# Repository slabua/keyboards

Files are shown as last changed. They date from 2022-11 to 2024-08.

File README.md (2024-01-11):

# Keyboards
[][GPLurl]

- [AtreuSLB50+](./atreuslb50+/)
  - A hand-wired custom Mechanical Keyboard based on the Raspberry Pi Pico.
- [JeegVa44 ErgoZero Split](./jeegva44ergozero/)
  - A split hand-wired custom Mechanical Keyboard based on the Waveshare RP2040-Zero.
- [Saru48W+](./saru48wplus/)
  - An ortholinear 13x4 hand-wired custom Mechanical Keyboard based on the nice!nano.

[GPLimg]: https://img.shields.io/badge/License-GPLv3-blue.svg
[GPLurl]: https://www.gnu.org/licenses/gpl-3.0

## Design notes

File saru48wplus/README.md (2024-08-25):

# Saru48W+ Mechanical Keyboard
[][GPLurl]
###### tags: `ZMK`
Status: Currently under development.

### An ortholinear 13x4 hand-wired custom Mechanical Keyboard based on the [nice!nano](https://nicekeyboards.com/nice-nano).

My third keyboard designed from scratch, this time with Bluetooth connectivity.

## Components
- 1x nice!nano (ZMK), USB-C and Bluetooth [[Buy]](https://nicekeyboards.com/nice-nano)
- 1x 3.7V 503040 600mAh LiPo battery [[Buy]](https://www.amazon.co.jp/gp/product/B07V22WWRJ)
- 48x switches [[Buy]](https://www.keychron.com/products/low-profile-gateron-mechanical-switch-set)
- 1x EC11 encoder [[Buy]](https://www.aliexpress.com/item/1005002358274622.html)
- 30x M2 5~6mm screws [[Buy]](https://www.amazon.co.jp/gp/product/B08KW4946Z)
- 6x M2 nuts [[Buy]](https://www.amazon.co.jp/dp/B096FKCZ5X)
- 12x M2 10mm stand-offs [[Buy]](https://www.amazon.co.jp/dp/B096FKCZ5X)
- 2x M4 Low profile brass heat inserts [[Buy]](https://www.amazon.co.jp/dp/B09HJY5717)
- 2x M4 6~8mm Socket cap head screws [[Buy]](https://www.amazon.co.jp/dp/B0BY8VXTLV)
- 1x micro switch (power) [[Buy]](https://www.amazon.co.jp/dp/B07F6WH8BV)
- 1x micro push button (bootsel, reset) [[Buy]](https://www.aliexpress.com/item/32907074501.html)
- 3D printed case, plate, feet

## Story
I wanted a more compact portable keyboard with Bluetooth connectivity and an encoder.
Different MCU, different firmware.

## Keymap (dev)
Keymap (http://www.keyboard-layout-editor.com/#/gists/8c13f3b0b67861c5a3c0984de046201e)

## Wiring
Wiring

## Repository
[https://github.com/slabua/keyboards/tree/main/saru48wplus](https://github.com/slabua/keyboards/tree/main/saru48wplus)

## Firmware
[https://github.com/slabua/zmk-config-saru48wplus](https://github.com/slabua/zmk-config-saru48wplus)

## 3D Model
3D model of Saru48W+ rev1 also available on:
Onshape: [[Link] (Coming Soon)](TODO)  
Thingiverse: https://www.thingiverse.com/thing:6428317  
Printables: https://www.printables.com/model/717305-saru48w-rev1

## Some photographs [[More]](./doc/photos.md)


## Build process [[More]](./doc/build.md)


## CAD renders [[More]](./doc/renders.md)


[GPLimg]: https://img.shields.io/badge/License-GPLv3-blue.svg
[GPLurl]: https://www.gnu.org/licenses/gpl-3.0

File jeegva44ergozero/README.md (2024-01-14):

# JeegVa44 ErgoZero Split Mechanical Keyboard
[][GPLurl]
###### tags: `Raspberry Pi` `RaspberryPi` `Raspberry` `Pi` `Pico` `RaspberryPiPico` `MicroPython`
Status: COMPLETED.

### A split hand-wired custom Mechanical Keyboard based on the [Waveshare RP2040-Zero](https://www.waveshare.com/rp2040-zero.htm).

My second keyboard designed from scratch, this time split.

## Components
- 2x RP2040 (KMK on Waveshare RP2040-Zero), USB-C port
- 44x switches
- 2x TRRS breakout boards
- 1x TRRS cable
- 28x M2 5mm screws
- 14x M2 10mm stand-offs
- 4x M4 Low profile brass heat inserts
- 4x M4 6~8mm Socket cap head screws
- 8x 10mm Rubber feet
- 46u Round hole female pin header
- 3D printed case, plate, feet

## Story
I wanted a portable split keyboard with a gentle vertical stagger, sixth column available and four thumb keys.
I also wanted to learn more about proper CAD design, so this time I ditched Blender and I designed everything from scratch in Onshape.

## Keymap (dev)
Keymap (http://www.keyboard-layout-editor.com/#/gists/682da89ee55639fe9fc0c6a14366d514)

## Repository
[https://github.com/slabua/keyboards/tree/main/jeegva44ergozero](https://github.com/slabua/keyboards/tree/main/jeegva44ergozero)

## 3D Model
3D model of JeegVa44 ErgoZero rev1 also available on:  
Onshape: [[Link]](https://cad.onshape.com/documents/5100a1aea8e406302df5bca3/w/c11b98ab1821eb9b6ec6d694/e/c7ba09cd25f0a52e98e90cc7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)  
Thingiverse: https://www.thingiverse.com/thing:5866262  
Printables: https://www.printables.com/model/404303-jeegva44-ergozero-rev1

## Some photographs and renders
















[GPLimg]: https://img.shields.io/badge/License-GPLv3-blue.svg
[GPLurl]: https://www.gnu.org/licenses/gpl-3.0

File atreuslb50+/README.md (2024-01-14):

# AtreuSLB50+ Mechanical Keyboard
[][GPLurl]
###### tags: `Raspberry Pi` `RaspberryPi` `Raspberry` `Pi` `Pico` `RaspberryPiPico` `MicroPython`
Status: COMPLETED.

### A hand-wired custom Mechanical Keyboard based on the [Raspberry Pi Pico](https://www.raspberrypi.org/products/raspberry-pi-pico/).

Finally I had the time to wrap up my little side project started about three months ago, and I thought to share it here. Although inspired by the Atreus, I couldn't quite find the right compromise among the non-split ergo keyboards, so I decided to make my own.

## Components
- 1x RP2040 (KMK on Raspberry Pi Pico), USB-C port
- 50x switches
- 1x SSD1306 128x64px 0.96in IIC OLED display
- 2x EC11 rotary encoders
- 1x EVQWGD001 rotary encoder
- 1x Pimoroni IIC trackball breakout
- 1x Active buzzer
- 2x micro push buttons (bootsel, reset)
- 3D printed case (5-10° tilt), plate, pcb

## Story
The design started from a semi-automated customised process by forking an OpenSCAD hotswap pcb generator repository, subsequently heavily worked on Blender. I had also added cutouts for per-key rgb, but in the end I gave up the idea of hand wiring the LEDs. At least in this version which, for me, has been an insightful experience.
I am slowly finalising the firmware configuration and I will eventually put it on github as usual. Wiring diagram and key layout will come along later.

## Keymap (dev)
Keymap (http://www.keyboard-layout-editor.com/#/gists/e1e9e5b6f24ec3cef3d0345b61fd87a2)

## Repository
[https://github.com/slabua/keyboards/tree/main/atreuslb50+](https://github.com/slabua/keyboards/tree/main/atreuslb50+)

## 3D Model
3D model of AtreuSLB50+ rev1 also available on:  
Thingiverse: https://www.thingiverse.com/thing:5458679  
Printables: https://www.printables.com/model/262446-atreuslb50-rev1

## Some photographs




















[GPLimg]: https://img.shields.io/badge/License-GPLv3-blue.svg
[GPLurl]: https://www.gnu.org/licenses/gpl-3.0

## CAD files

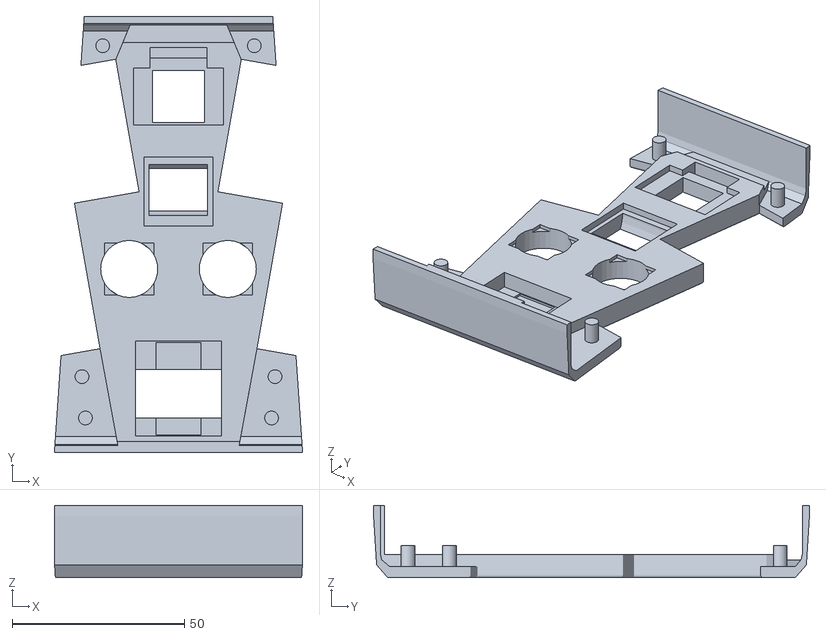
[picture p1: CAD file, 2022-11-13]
atreuslb50+/cad/rev1/AtreuSLB50-TopCenter.stl
72.0 x 126.5 x 21.0

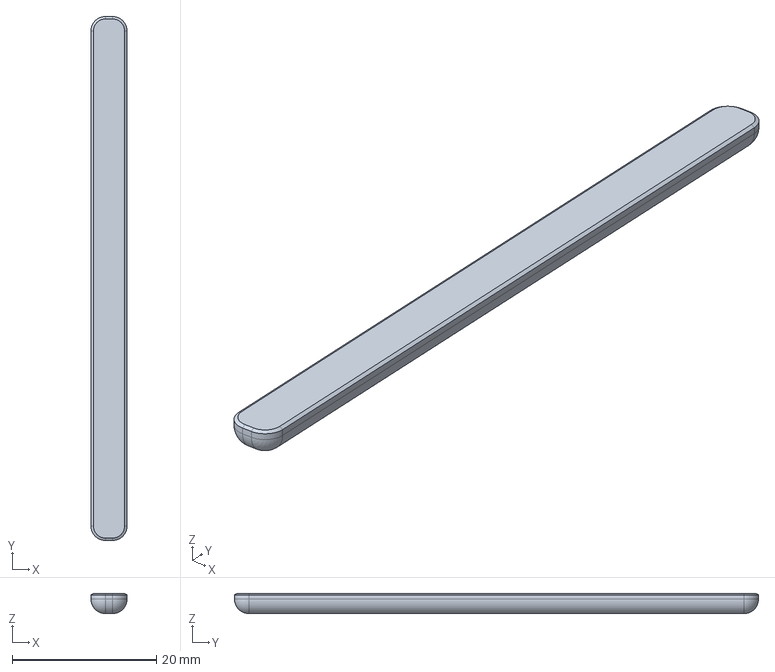
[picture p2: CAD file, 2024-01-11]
saru48wplus/cad/rev1/step/Saru48wPlus - FootLow.step
5.00 x 72.6 x 2.80 mm

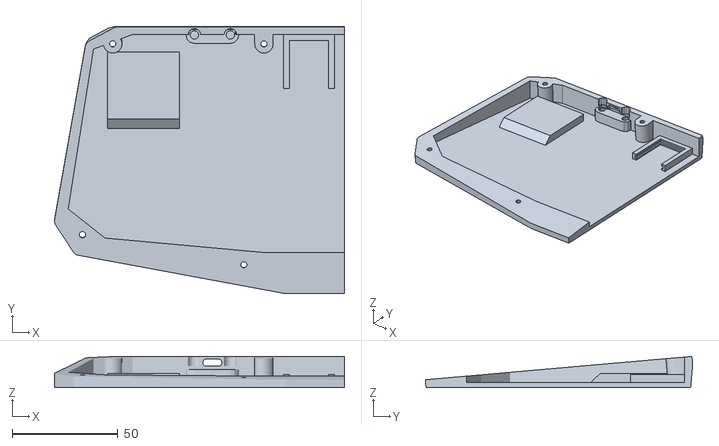
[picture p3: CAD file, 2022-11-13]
atreuslb50+/cad/rev1/AtreuSLB50-BottomLeft.stl
137.0 x 126.4 x 14.7

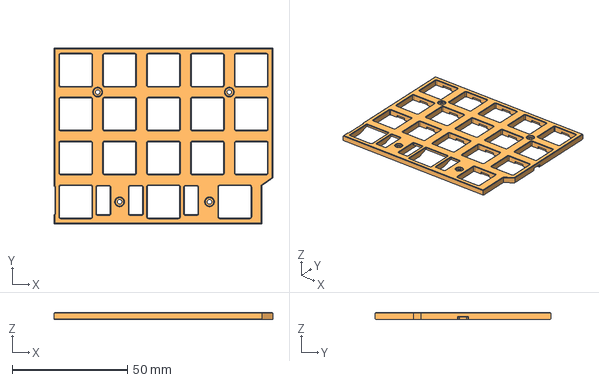
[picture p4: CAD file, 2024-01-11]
saru48wplus/cad/rev1/step/Saru48wPlus - PlateC (CherryMX).step
95.0 x 76.2 x 3.00 mm

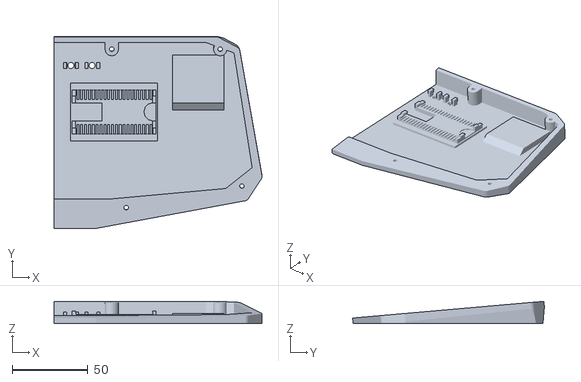
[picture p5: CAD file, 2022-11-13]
atreuslb50+/cad/rev1/AtreuSLB50-BottomRight.stl
137.0 x 126.4 x 14.7

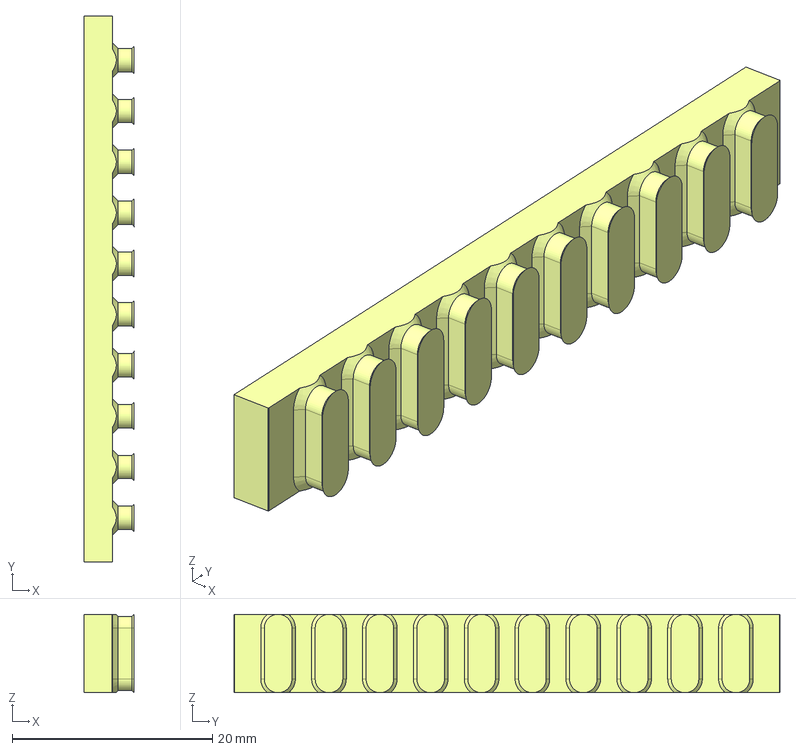
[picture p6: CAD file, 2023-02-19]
jeegva44ergozero/cad/rev1/step/JeegVa44ErgoZero-SlitsCoverR.step
5.00 x 54.5 x 7.84 mm

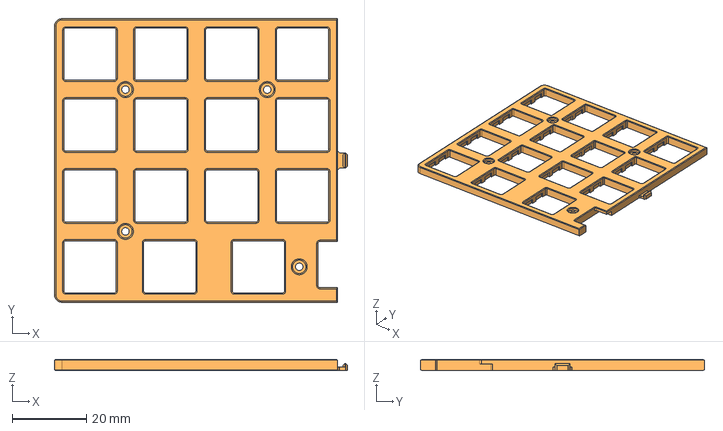
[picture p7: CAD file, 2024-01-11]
saru48wplus/cad/rev1/step/Saru48wPlus - PlateL (GateronLowProfile).step
78.7 x 76.2 x 3.00 mm

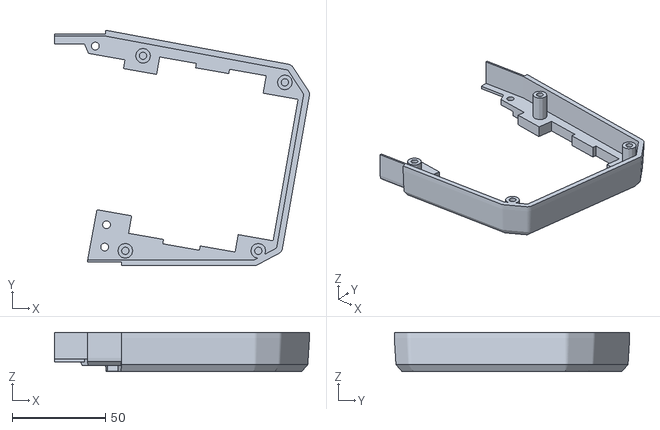
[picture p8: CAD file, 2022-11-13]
atreuslb50+/cad/rev1/AtreuSLB50-TopRight.stl
137.0 x 126.5 x 21.0

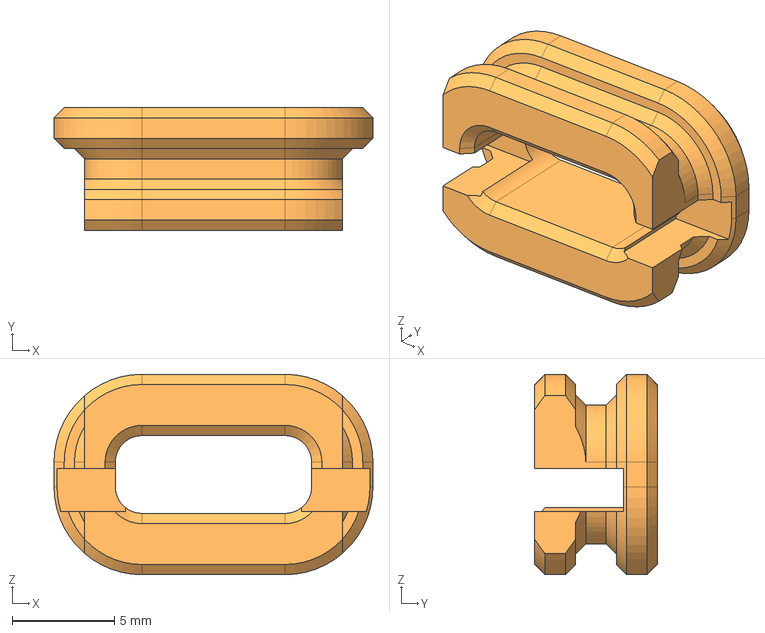
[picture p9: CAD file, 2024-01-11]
saru48wplus/cad/rev1/step/Saru48wPlus - USB Ring.step
15.6 x 6.00 x 9.80 mm

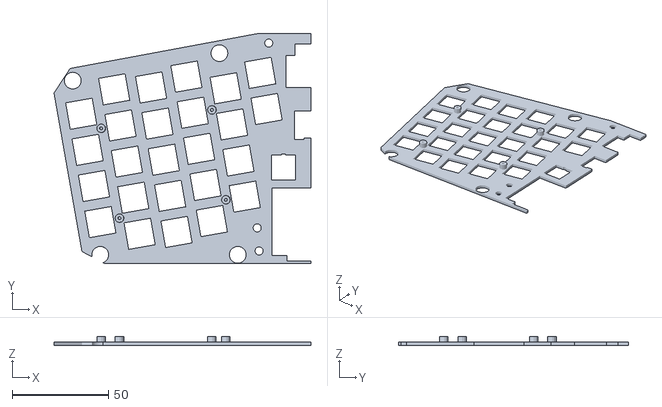
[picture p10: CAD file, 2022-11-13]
atreuslb50+/cad/rev1/AtreuSLB50-PlateLeft.stl
133.5 x 119.5 x 4.80

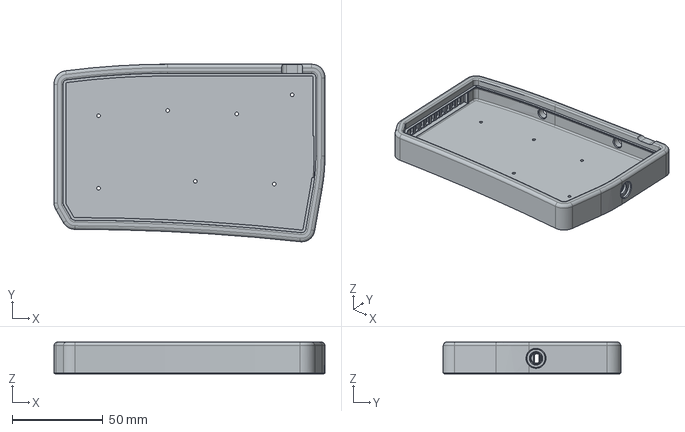
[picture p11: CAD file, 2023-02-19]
jeegva44ergozero/cad/rev1/step/JeegVa44ErgoZero-CaseL.step
149.4 x 97.9 x 17.6 mm

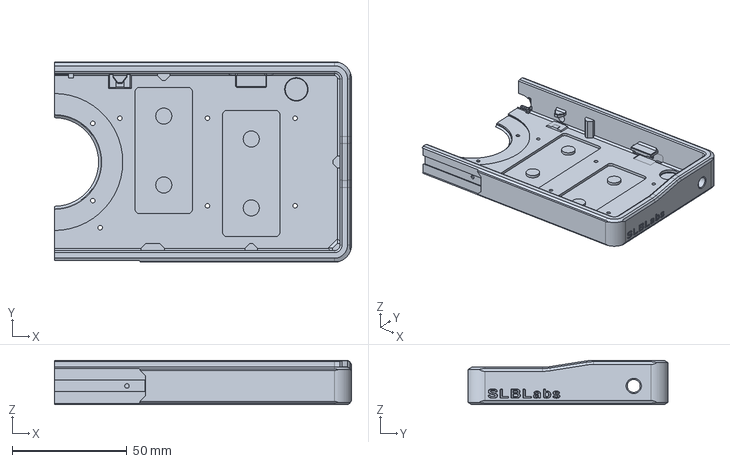
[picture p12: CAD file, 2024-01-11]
saru48wplus/cad/rev1/step/Saru48wPlus - CaseR.step
129.2 x 87.2 x 19.3 mm

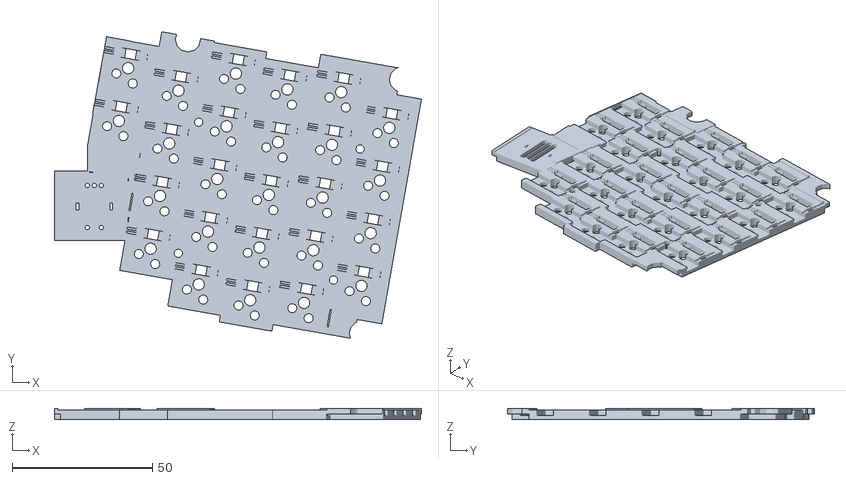
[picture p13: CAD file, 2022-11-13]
atreuslb50+/cad/rev1/AtreuSLB50-PcbRight.stl
130.7 x 109.2 x 4.00

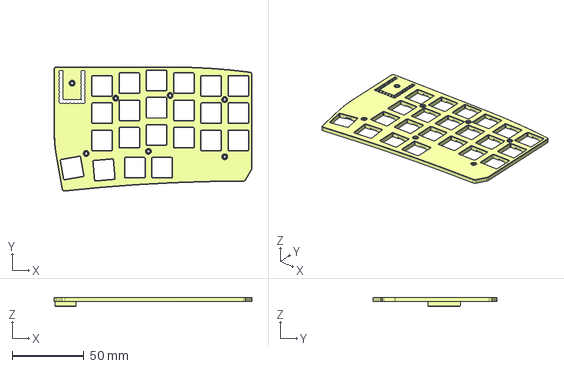
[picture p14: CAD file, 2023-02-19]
jeegva44ergozero/cad/rev1/step/JeegVa44ErgoZero-PlateR.step
138.4 x 86.9 x 6.50 mm

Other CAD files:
jeegva44ergozero/cad/rev1/step/JeegVa44ErgoZero-CaseR-noSlits.step
jeegva44ergozero/cad/rev1/step/JeegVa44ErgoZero-CaseL-noSlits.step
jeegva44ergozero/cad/rev1/step/JeegVa44ErgoZero-SlitsCoverL.step
saru48wplus/cad/rev1/step/Saru48wPlus - PlateC (GateronLowProfile).step
atreuslb50+/cad/rev1/AtreuSLB50-Foot.stl
atreuslb50+/cad/rev1/AtreuSLB50-PcbLeft.stl
atreuslb50+/cad/rev1/AtreuSLB50-PlateRight.stl
atreuslb50+/cad/rev1/AtreuSLB50-TopLeft.stl
jeegva44ergozero/cad/rev1/step/JeegVa44ErgoZero-CaseR.step
jeegva44ergozero/cad/rev1/step/JeegVa44ErgoZero-ErgoFoot.step
jeegva44ergozero/cad/rev1/step/JeegVa44ErgoZero-PlateL.step
jeegva44ergozero/cad/rev1/stl/JeegVa44ErgoZero-ErgoFoot.stl
jeegva44ergozero/cad/rev1/stl/JeegVa44ErgoZero-SlitsCoverL.stl
jeegva44ergozero/cad/rev1/stl/JeegVa44ErgoZero-SlitsCoverR.stl
saru48wplus/cad/rev1/step/Saru48wPlus - Badge.step
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













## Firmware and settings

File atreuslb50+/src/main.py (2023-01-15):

import board
import pwmio
import time

from kb import KMKKeyboard
# import logos

from kmk.consts import UnicodeMode
from kmk.handlers.sequences import compile_unicode_string_sequences as cuss
from kmk.handlers.sequences import send_string
from kmk.keys import KC

from kmk.extensions.buzzer import BuzzerType
from kmk.extensions.lock_status import LockStatus
from kmk.extensions.media_keys import MediaKeys
from kmk.extensions.oled_1306 import DisplayOLED, LogoScene, StatusScene  # , KeypressesScene
# from kmk.extensions.RGB import RGB
# from kmk.extensions.wpm import WPM
from kmk.modules.encoder import EncoderHandler
from kmk.modules.layers import Layers
from kmk.modules.modtap import ModTap
from kmk.modules.mouse_keys import MouseKeys
from kmk.modules.oneshot import OneShot
from kmk.modules.pimoroni_trackball import Trackball, TrackballMode, PointingHandler, KeyHandler, ScrollHandler, ScrollDirection
from kmk.modules.tapdance import TapDance
from micropython import const

import busio as io
i2c = io.I2C(scl=board.GP1, sda=board.GP0)

keyboard = KMKKeyboard()

# Extensions
buzzertype = BuzzerType(enabled=False)
locks = LockStatus()
mediakeys = MediaKeys()
# rgb = RGB(pixel_pin=14, num_pixels=1)
# wpm = WPM(debug=False)
keyboard.extensions = [locks, mediakeys, buzzertype]  # , wpm]  # , rgb]
# keyboard.extensions = [locks, mediakeys]  # , wpm]  # , rgb]

# Modules
layers = Layers()
modtap = ModTap()
modtap.tap_time = 250
mousekeys = MouseKeys()
oneshot = OneShot()
oneshot.tap_time = 1000
tapdance = TapDance()
tapdance.tap_time = 750

# Rotary encoders
encoders = EncoderHandler()
encoders.pins = (
    (board.GP14, board.GP15, None, False, 4),  # encoder L
    (board.GP17, board.GP16, None, False, 4),  # encoder R
    (board.GP12, board.GP13, None, False, 2),  # roller
)

# Trackball
trackball = Trackball(i2c, mode=TrackballMode.MOUSE_MODE, handlers=[
    PointingHandler(),
    # on layer 1 and above use the default pointing behavior
    ScrollHandler(scroll_direction=ScrollDirection.REVERSE),
    # act like an encoder, input arrow keys
    KeyHandler(KC.UP, KC.RIGHT, KC.DOWN, KC.LEFT, KC.ENTER),
])

# OLED
layers_names = ['0. Qwerty', '1. Fun | Num', '2. Sym | Nav',
                '3. Emoji', '4. Tarmak3', '5. Tarmak4', '6. Colemak']
slblabs_logo = const(
    0x00000000000000000000000000000000000000000000000000000000000000000000c0e0f0f87c3c0c0602000000000000008080808080c0404020000000000000000000000000000000000000000000000000000000000000000000000000000000000000000000000000000000000000000000000000000000000000000000000000000000000000000000000000c0e0f0f038180c0c040404000000000000f8ffff0f010000000000000004020303030303010101000000000000000000000080c0e0f0f0f0f0f0f0f0f0f0f0f0e0e0c080000000f0f0f0f0e00000000000000000000000000000f0f0f0f0f0707070707070f0f0f0f0e0c08000000000000000000000000000000000000000000f1f3f3c38706060404000000000000000ffff1f00000000020286cefefcfc78300000000000000000000000000000000000070f1f1f3f3c3c78787878f8f0f1f3e3e3c3000000ffffffffff0000000000000000000000000000ffffffffff38383838383838387fffffffe780000000000000000000000000000000000000000000000000000000808080c040406060b0fff718180c0c0e06078383818180000020206060e0c0c0c0c08080000000000000070f1f3f3e3c3c3c3c3c3c3c3c3f3f1f1f0f0100003f3f3f3f3f3c3c3c3c3c3c3c3c3c3c3c3800003f3f3f3f3f383838383838383c3c3f1f1f0f030000000000000000000000000000000000040404020202030101010100000000000000ffff01000000000000000000818183c79ffefefcf8f09f3f3f1f1f0f0700000000000080c0c0c08000000000000000000000000000000000000000000000000000c0c0c0c000000000000000000000000000000000000000000000000000000000000000000000000000008000004040404040202020202030301010181898fb0f0c0c0c04060606070303038381c1f1fc7f7f3f1f0f01000000000000000000000000ffffffffff000000000000000000000080dcdedeceeeeeeefefcfcf80000ffffffff0e0e0e0e1efefcf8f000003c7cfefeeecececede9c9c00000000000000000000000040602030301818181c1c1c1c06060200000000000080f80f0100000000000000000000000101010100000000000000000000000000000000000000000f1f1f1f1f1c1c1c1c1c1c1c1c1c1c000f0f1f1f1818181c0f1f1f1f00000f0f1f1f1c1c1c1c1e1f0f070300000e0e1e1c1c1c1d1d1f0f0f0200000000000000000000000000000000000000000000000000000000000000080300000000000000000000000000000000000000000000000000000000000000000000000000000000000000000000000000000000000000000000000000000000000000000000000000000000000000000000000000000000000000000000000000000000)
# slblabs_logo_inv = const(
#    0xffffffffffffffffffffffffffffffffffffffffffffffffffffffffffffffffffff3f1f0f0783c3f3f9fdffffffffffffff7f7f7f7f7f3fbfbfdfffffffffffffffffffffffffffffffffffffffffffffffffffffffffffffffffffffffffffffffffffffffffffffffffffffffffffffffffffffffffffffffffffffffffffffffffffffffffffffffffffffffff3f1f0f0fc7e7f3f3fbfbfbffffffffffff070000f0fefffffffffffffffbfdfcfcfcfcfcfefefeffffffffffffffffffffff7f3f1f0f0f0f0f0f0f0f0f0f0f0f1f1f3f7fffffff0f0f0f0f1fffffffffffffffffffffffffffff0f0f0f0f0f8f8f8f8f8f8f0f0f0f0f1f3f7ffffffffffffffffffffffffffffffffffffffffff0e0c0c3c78f9f9fbfbfffffffffffffff0000e0fffffffffdfd793101030387cffffffffffffffffffffffffffffffffffff8f0e0e0c0c3c387878787070f0e0c1c1c3cffffff0000000000ffffffffffffffffffffffffffff0000000000c7c7c7c7c7c7c7c780000000187fffffffffffffffffffffffffffffffffffffffffffffffffffffff7f7f7f3fbfbf9f9f4f0008e7e7f3f3f1f9f87c7c7e7e7fffffdfdf9f9f1f3f3f3f3f7f7ffffffffffffff8f0e0c0c1c3c3c3c3c3c3c3c3c0c0e0e0f0feffffc0c0c0c0c0c3c3c3c3c3c3c3c3c3c3c3c7ffffc0c0c0c0c0c7c7c7c7c7c7c7c3c3c0e0e0f0fcfffffffffffffffffffffffffffffffffffbfbfbfdfdfdfcfefefefeffffffffffffff0000feffffffffffffffffff7e7e7c3860010103070f60c0c0e0e0f0f8ffffffffffff7f3f3f3f7fffffffffffffffffffffffffffffffffffffffffffffffffff3f3f3f3fffffffffffffffffffffffffffffffffffffffffffffffffffffffffffffffffffffffffffff7fffffbfbfbfbfbfdfdfdfdfdfcfcfefefe7e76704f0f3f3f3fbf9f9f9f8fcfcfc7c7e3e0e038080c0e0f0feffffffffffffffffffffffff0000000000ffffffffffffffffffffff7f2321213111111101030307ffff00000000f1f1f1f1e10103070fffffc383010111313131216363ffffffffffffffffffffffffbf9fdfcfcfe7e7e7e3e3e3e3f9f9fdffffffffffff7f07f0fefffffffffffffffffffffffefefefefffffffffffffffffffffffffffffffffffffffff0e0e0e0e0e3e3e3e3e3e3e3e3e3e3fff0f0e0e0e7e7e7e3f0e0e0e0fffff0f0e0e0e3e3e3e3e1e0f0f8fcfffff1f1e1e3e3e3e2e2e0f0f0fdfffffffffffffffffffffffffffffffffffffffffffffffffffffffffffffff7fcffffffffffffffffffffffffffffffffffffffffffffffffffffffffffffffffffffffffffffffffffffffffffffffffffffffffffffffffffffffffffffffffffffffffffffffffffffffffffffffffffffffffffffffffffffffffffffffffffffffff)
# slblabs_logo_v2 = const(
#    0x000000000000000000000000000080c0c0e0e0f0f0f0f83808000000f8fcfcfc00000000000000000000000000000000000000000000000000000000000000000000000000000000000000000000000000000000000000000000000000000000fcfcfcf80000000838f8f0f0f0e0e0c0c080000000000000000000000000000000000000000080c0e0f0fcfcfeffffffff7f3f1f0703000000000000ffffffff000000e0f8fcfcfefe9e1e1e1e1e3e3e7e7cfcf870000000fefefefefc00000000000000000000000000fcfefefefe1e1e1e1e1e1e1ebefefcfcf8e000000000ffffffff00000000000003071f3f7ffffffffffefcfcf0e0c080000000000000000000c0f8feffffffffffff9f0f0701000000000000000000000000ffffffff000000c0e3e7e7c78f8f8f8f9f9f9ebefefefcfcf8e00000ffffffffff80808080808080808080000000ffffffffff8f0f0f0f0f0f0f8ffffffffff860000000ffffffff00000000000000000000000001070f7ffffffffffffffef8c000000000007e7fffffffffffffffffffffffffffffffffffffffff0f070000ffffffff00000000030307070707070707070707070707030300000007070707070707070707070707070707020007070707070707070707070707070707030100000000ffffffff0000070ffffffffffffffffffffffefefcf9f9f3e3e7c7c38380000000000080000000000000000000000000000000000000000000000000ffffffff00000000000000000000000000000000000000000000000000000000000000000000000000000000000000000000000000000000000000000000000000000000ffffffff000000000001030307070f1f1f3f3f7f7fffffffffffffffff7f0000000000031f7ffefefcfcf8f0f0e0c080000000000000000000000000ffffffff000000000000fefffffffe0000000000000000000060707078383838f8f0f0e00000ffffffff70383878f0f0e0c000e0f0f0f8b8383870707060000000000000ffffffff00000000000000000000000080e0f0f8feffffffffff7f1f030000000000000000000103070f3f3f7ffffffffffefefcf8f0f0e0e0e00000ffffffff0000000000003f7f7f7f7f787878787878787870083e7f7f777777773f7f7f7f00003f7f7f7f707070787f3f3f0f00393b7b737777777f7f3e1c000000000000ffffffff0000e0e0e0f0f0f8fcfefeffffffff7f3f3f0f070301000000000000000000000000000000000000000001030307070f0f0f1f1f1f3f00003f3f3f3f000000000000000000000000000000000000000000000000000000000000000000000000000000000000000000000000000000000000000000000000000000003f3f3f3f00003f1f1f1f0f0f0f07070303010000000000000000000000000000)
# slblabs_logo_v2_inv = const(
#    0xffffffffffffffffffffffffffff7f3f3f1f1f0f0f0f07c7f7ffffff07030303ffffffffffffffffffffffffffffffffffffffffffffffffffffffffffffffffffffffffffffffffffffffffffffffffffffffffffffffffffffffffffffffff03030307fffffff7c7070f0f0f1f1f3f3f7fffffffffffffffffffffffffffffffffffffffff7f3f1f0f0303010000000080c0e0f8fcffffffffffff00000000ffffff1f070303010161e1e1e1e1c1c1818303078fffffff0101010103ffffffffffffffffffffffffff0301010101e1e1e1e1e1e1e141010303071fffffffff00000000fffffffffffffcf8e0c080000000000103030f1f3f7fffffffffffffffffff3f070100000000000060f0f8feffffffffffffffffffffffff00000000ffffff3f1c181838707070706060614101010303071fffff00000000007f7f7f7f7f7f7f7f7f7fffffff000000000070f0f0f0f0f0f07000000000079fffffff00000000fffffffffffffffffffffffffef8f08000000000000001073fffffffffff81800000000000000000000000000000000000000000f0f8ffff00000000fffffffffcfcf8f8f8f8f8f8f8f8f8f8f8f8f8fcfcfffffff8f8f8f8f8f8f8f8f8f8f8f8f8f8f8f8fdfff8f8f8f8f8f8f8f8f8f8f8f8f8f8f8f8fcfeffffffff00000000fffff8f00000000000000000000001010306060c1c18383c7c7fffffffffff7fffffffffffffffffffffffffffffffffffffffffffffffff00000000ffffffffffffffffffffffffffffffffffffffffffffffffffffffffffffffffffffffffffffffffffffffffffffffffffffffffffffffffffffffffffffffff00000000fffffffffffefcfcf8f8f0e0e0c0c08080000000000000000080fffffffffffce08001010303070f0f1f3f7fffffffffffffffffffffffff00000000ffffffffffff0100000001ffffffffffffffffffff9f8f8f87c7c7c7070f0f1fffff000000008fc7c7870f0f1f3fff1f0f0f0747c7c78f8f8f9fffffffffffff00000000ffffffffffffffffffffffff7f1f0f0701000000000080e0fcfffffffffffffffffffefcf8f0c0c08000000000010103070f0f1f1f1fffff00000000ffffffffffffc08080808087878787878787878ff7c1808088888888c0808080ffffc08080808f8f8f8780c0c0f0ffc6c4848c8888888080c1e3ffffffffffff00000000ffff1f1f1f0f0f070301010000000080c0c0f0f8fcfefffffffffffffffffffffffffffffffffffffffffefcfcf8f8f0f0f0e0e0e0c0ffffc0c0c0c0ffffffffffffffffffffffffffffffffffffffffffffffffffffffffffffffffffffffffffffffffffffffffffffffffffffffffffffffffffffffffffffffffc0c0c0c0ffffc0e0e0e0f0f0f0f8f8fcfcfeffffffffffffffffffffffffffff)

scenes = [
    # LogoScene(logos.slblabs_logo_16),
    LogoScene(slblabs_logo),
    StatusScene(layers_names=layers_names, separate_default_layer=True, rgb_ext=None),
    # LogoScene(slblabs_logo_v2),
    # LogoScene(slblabs_logo_v2_inv),
    # LogoScene(slblabs_logo_inv),
    # KeypressesScene(matrix_width=12, matrix_height=5, split=False,),
]
oled = DisplayOLED(i2c, scenes, flip=False)

keyboard.modules = [layers, modtap, mousekeys,
                    oneshot, encoders, tapdance, trackball, oled]

keyboard.debug_enabled = False
keyboard.tap_time = 100
keyboard.unicode_mode = UnicodeMode.LINUX

# Filler keys
_______ = KC.TRNS
XXXXXXX = KC.NO

# Custom keys
LSFTALT = KC.MT(KC.LSFT, KC.LALT, prefer_hold=False,
                tap_interrupted=False, tap_time=200)
LSFTCTL = KC.MT(KC.LSFT, KC.LCTRL, prefer_hold=False,
                tap_interrupted=False, tap_time=200)
APPRGUI = KC.MT(KC.APP, KC.RGUI, prefer_hold=False,
                tap_interrupted=False, tap_time=200)
OSLSFT = KC.OS(KC.LSFT)
LALTAGR = KC.TD(KC.LALT, KC.RALT)
RALTAGR = KC.TD(KC.RALT, KC.RGUI)

LOWER = KC.MO(1)
RAISE = KC.MO(2)
ADJUST = KC.LT(3, KC.LGUI)

BASE = KC.DF(0)

UNDO = KC.LCTRL(KC.Z)
REDO = KC.LCTRL(KC.Y)
ZOOM_IN = KC.LCTRL(KC.EQUAL)
ZOOM_OUT = KC.LCTRL(KC.MINUS)
ZOOM_RST = KC.LCTRL(KC.N0)

emoji = cuss({
    # Emoji
    'BEER': r'🍺',
    'BEER_TOAST': r'🍻',
    'FACE_CUTE_SMILE': r'😊',
    'FACE_HEART_EYES': r'😍',
    'FACE_JOY': r'😂',
    'FACE_SWEAT_SMILE': r'😅',
    'FACE_THINKING': r'🤔',
    'FIRE': r'🔥',
    'FLAG_CA': r'🇨🇦',
    'FLAG_US': r'🇺🇸',
    'HAND_CLAP': r'👏',
    'HAND_HORNS': r'🤘',
    'HAND_OK': r'👌',
    'HAND_THUMB_DOWN': r'👎',
    'HAND_THUMB_UP': r'👍',
    'HAND_WAVE': r'👋',
    'HEART': r'❤️',
    'MAPLE_LEAF': r'🍁',
    'PIEN': r'🥺',
    'POOP': r'💩',
    'TADA': r'🎉',

    # Kaomoji
    'ANGRY_TABLE_FLIP': r'(ノಠ痊ಠ)ノ彡┻━┻',
    'CELEBRATORY_GLITTER': r'+｡:.ﾟヽ(´∀｡)ﾉﾟ.:｡+ﾟﾟ+｡:.ﾟヽ(*´∀)ﾉﾟ.:｡+ﾟ',
    'SHRUGGIE': r'¯\_(ツ)_/¯',
    'TABLE_FLIP': r'(╯°□°）╯︵ ┻━┻',
})

# flake8: noqa
# Keyboard mapping
keyboard.keymap = [

    [  # base: qwerty (test)
        KC.Q,      KC.W,      KC.E,      KC.R,      KC.T,      KC.OLED_TOG,           KC.MUTE,   KC.Y,      KC.U,      KC.I,     KC.O,      KC.P,
        KC.A,      KC.S,      KC.D,      KC.F,      KC.G,      KC.TB_NEXT_HANDLER,               KC.H,      KC.J,      KC.K,     KC.L,      KC.SCLN,
        KC.Z,      KC.X,      KC.C,      KC.V,      KC.B,      KC.LBRC,               KC.RBRC,   KC.N,      KC.M,      KC.COMM,  KC.DOT,    KC.SLSH,
        LSFTALT,   OSLSFT,    KC.TAB,    KC.LALT,   KC.LCTRL,  KC.SPC,                KC.RSFT,   KC.BSPC,   RALTAGR,   KC.MINUS, KC.RSFT,   KC.ENT,
        KC.GESC,   ADJUST,    LOWER,                                                                        RAISE,     APPRGUI,  KC.QUOT,
    ],


    [  # lower: fn/num
        KC.F1,     KC.F2,     KC.F3,     KC.F4,     KC.F5,     _______,               ZOOM_RST,  KC.PAST,   KC.N7,     KC.N8,    KC.N9,     KC.BSPC,
        KC.F6,     KC.F7,     KC.F8,     KC.F9,     KC.F10,    _______,                          KC.PSLS,   KC.N4,     KC.N5,    KC.N6,     KC.PMNS,
        XXXXXXX,   XXXXXXX,   XXXXXXX,   KC.F11,    KC.F12,    KC.GRV,                KC.BSLS,   KC.INS,    KC.N1,     KC.N2,    KC.N3,     KC.PPLS,
        _______,   _______,   _______,   _______,   _______,   KC.MB_LMB,             KC.MB_RMB, _______,   KC.LPRN,   KC.N0,    KC.RPRN,   _______,
        _______,   _______,   XXXXXXX,                                                                      XXXXXXX,   KC.EQL,   KC.DEL,
    ],

    [  # raise: sym/nav
        KC.EXLM,   KC.CIRC,   KC.AMPR,   KC.DLR,    KC.PERC,   _______,               ZOOM_RST,  KC.VOLU,   UNDO,      REDO,     KC.HOME,   KC.BSPC,
        XXXXXXX,   XXXXXXX,   XXXXXXX,   XXXXXXX,   XXXXXXX,   _______,                          KC.VOLD,   XXXXXXX,   XXXXXXX,  KC.END,    KC.PGUP,
        XXXXXXX,   XXXXXXX,   XXXXXXX,   XXXXXXX,   XXXXXXX,   KC.AT,                 KC.HASH,   KC.MUTE,   XXXXXXX,   KC.UP,    XXXXXXX,   KC.PGDOWN,
        XXXXXXX,   _______,   _______,   _______,   _______,   KC.NLCK,               KC.CAPS,   KC.PSCR,   KC.LEFT,   KC.DOWN,  KC.RIGHT,  _______,
        _______,   BASE,      XXXXXXX,                                                                      XXXXXXX,   XXXXXXX,  KC.DEL,
    ],

    [  # adjust: emoji
        KC.Q,      KC.W,      KC.E,      KC.R,      KC.T,      KC.TB_NEXT_HANDLER,    KC.MUTE,   KC.Y,      KC.U,      KC.I,     KC.O,      KC.P,
        KC.A,      KC.S,      KC.D,      KC.F,      KC.G,      KC.OLED_TOG,                      KC.H,      KC.J,      KC.K,     KC.L,      KC.SCLN,
        KC.Z,      KC.X,      KC.C,      KC.V,      KC.B,      KC.LBRC,               KC.RBRC,   KC.N,      KC.M,      KC.COMM,  KC.DOT,    KC.SLSH,
        LSFTCTL,   KC.TAB,    OSLSFT,    KC.CAPS,   LALTAGR,   KC.SPC,                KC.SPC,    KC.RALT,   KC.BSPC,   KC.RSFT,  KC.MINUS,  emoji.PIEN,
        KC.GESC,   XXXXXXX,   LOWER,                                                                        XXXXXXX,   COLEMAK,  BASE,
    ],

]

# Encoders mapping
encoders.map = [
    (  # base: qwerty
        (KC.OLED_PRV, KC.OLED_NXT, None,),
        (KC.VOLD, KC.VOLU, None,),
        (KC.PGDOWN, KC.PGUP, None,),
    ),
    (  # lower: sym/nav
        (_______, _______, None,),
        (_______, _______, None,),
        (ZOOM_OUT, ZOOM_IN, None,),
    ),
    (  # raise: fn/num
        (_______, _______, None,),
        (_______, _______, None,),
        (ZOOM_OUT, ZOOM_IN, None,),
    ),
    (  # adjust: emoji
        (_______, _______, None,),
        (_______, _______, None,),
        (ZOOM_OUT, ZOOM_IN, None,),
    ),
]

# Trackball setup
trackball.set_rgbw(255, 128, 0, 0)
time.sleep(0.25)
trackball.set_rgbw(4, 8, 32, 0)

# Buzzer
"""
buzzer = pwmio.PWMOut(board.GP9, variable_frequency=True)
OFF = 0
ON = 2**15
buzzer.duty_cycle = ON
buzzer.frequency = 2000
time.sleep(0.1)
buzzer.frequency = 1000
time.sleep(0.1)
buzzer.duty_cycle = OFF
"""

# Main
if __name__ == '__main__':
    print(keyboard.extensions)
    print(keyboard.modules)
    keyboard.go()

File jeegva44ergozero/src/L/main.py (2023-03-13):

import board

from kb import KMKKeyboard
# from kb import data_pin

from kmk.consts import UnicodeMode
from kmk.handlers.sequences import compile_unicode_string_sequences as cuss
from kmk.handlers.sequences import send_string
from kmk.keys import KC

from kmk.extensions.lock_status import LockStatus
from kmk.extensions.media_keys import MediaKeys
from kmk.extensions.RGB import RGB
from kmk.extensions.rgb import AnimationModes
# from kmk.extensions.wpm import WPM
from kmk.modules.layers import Layers
from kmk.modules.modtap import ModTap
from kmk.modules.mouse_keys import MouseKeys
from kmk.modules.oneshot import OneShot
from kmk.modules.split import Split, SplitType, SplitSide
from kmk.modules.tapdance import TapDance


keyboard = KMKKeyboard()
keyboard.debug_enabled = True

# Extensions
locks = LockStatus()
mediakeys = MediaKeys()
rgb = RGB(
    pixel_pin=board.GP16,
    num_pixels=1,
    val_limit=5,
    hue_default=40,
    sat_default=255,
    rgb_order=(1, 0, 2),  # GRB WS2812
    val_default=10,
    hue_step=1,
    sat_step=1,
    val_step=1,
    animation_speed=10,
    breathe_center=1,  # 1.0-2.7
    knight_effect_length=3,
    animation_mode=AnimationModes.STATIC,
    reverse_animation=False,
    refresh_rate=60,
)
# wpm = WPM(debug=False)
keyboard.extensions = [locks, mediakeys, rgb]  # , wpm]  # , rgb]

# Modules
layers = Layers()
modtap = ModTap()
modtap.tap_time = 250
mousekeys = MouseKeys()
oneshot = OneShot()
oneshot.tap_time = 1000
split = Split(
    split_type=SplitType.UART,
    split_side=SplitSide.LEFT,
    # split_target_left=True,
    data_pin=board.GP0,
    data_pin2=board.GP1,
    use_pio=True,
    uart_flip=True,
)
tapdance = TapDance()
tapdance.tap_time = 750

keyboard.modules = [layers, modtap, mousekeys, oneshot, split, tapdance]

keyboard.debug_enabled = False
keyboard.tap_time = 100
keyboard.unicode_mode = UnicodeMode.LINUX

# Filler keys
_______ = KC.TRNS
XXXXXXX = KC.NO

# Custom keys
LSFTALT = KC.MT(KC.LSFT, KC.LALT, prefer_hold=False,
                tap_interrupted=False, tap_time=200)
LSFTCTL = KC.MT(KC.LSFT, KC.LCTRL, prefer_hold=False,
                tap_interrupted=False, tap_time=200)
APPRGUI = KC.MT(KC.APP, KC.RGUI, prefer_hold=False,
                tap_interrupted=False, tap_time=200)
OSLSFT = KC.OS(KC.LSFT)
LALTAGR = KC.TD(KC.LALT, KC.RALT)
LALTGUI = KC.TD(KC.LALT, KC.LGUI)
RALTAGR = KC.TD(KC.RALT, KC.RGUI)
RALTGRA = KC.TD(KC.RGUI, KC.RALT)

LOWER = KC.MO(1)
RAISE = KC.MO(2)
ADJUST = KC.LT(3, KC.LGUI)

BASE = KC.DF(0)

UNDO = KC.LCTRL(KC.Z)
REDO = KC.LCTRL(KC.Y)
ZOOM_IN = KC.LCTRL(KC.EQUAL)
ZOOM_OUT = KC.LCTRL(KC.MINUS)
ZOOM_RST = KC.LCTRL(KC.N0)
PREVWRD = KC.LCTRL(KC.LEFT)
NEXTWRD = KC.LCTRL(KC.RIGHT)

emoji = cuss({
    # Emoji
    'BEER': r'🍺',
    'BEER_TOAST': r'🍻',
    'FACE_CUTE_SMILE': r'😊',
    'FACE_HEART_EYES': r'😍',
    'FACE_JOY': r'😂',
    'FACE_SWEAT_SMILE': r'😅',
    'FACE_THINKING': r'🤔',
    'FIRE': r'🔥',
    'HAND_CLAP': r'👏',
    'HAND_HORNS': r'🤘',
    'HAND_OK': r'👌',
    'HAND_THUMB_DOWN': r'👎',
    'HAND_THUMB_UP': r'👍',
    'HAND_WAVE': r'👋',
    'HEART': r'❤️',
    'PIEN': r'🥺',
    'POOP': r'💩',
    'TADA': r'🎉',

    # Kaomoji
    'ANGRY_TABLE_FLIP': r'(ノಠ痊ಠ)ノ彡┻━┻',
    'CELEBRATORY_GLITTER': r'+｡:.ﾟヽ(´∀｡)ﾉﾟ.:｡+ﾟﾟ+｡:.ﾟヽ(*´∀)ﾉﾟ.:｡+ﾟ',
    'SHRUGGIE': r'¯\_(ツ)_/¯',
    'TABLE_FLIP': r'(╯°□°）╯︵ ┻━┻',
})

# flake8: noqa
# Keyboard mapping
keyboard.keymap = [

    [  # base: qwerty
        KC.GESC,   KC.Q,      KC.W,      KC.E,      KC.R,      KC.T,                            KC.Y,      KC.U,      KC.I,     KC.O,      KC.P,      KC.MINUS,
        KC.TAB,    KC.A,      KC.S,      KC.D,      KC.F,      KC.G,                            KC.H,      KC.J,      KC.K,     KC.L,      KC.SCLN,   KC.QUOT,
        KC.LSFT,   KC.Z,      KC.X,      KC.C,      KC.V,      KC.B,                            KC.N,      KC.M,      KC.COMM,  KC.DOT,    KC.SLSH,   KC.RSFT,
        LALTGUI,   LOWER,     KC.LCTRL,  KC.SPC,                                                KC.ENT,    KC.BSPC,   RAISE,    RALTGRA,
    ],

    # [  # lower: sym/num
    #     _______,   KC.N1,     KC.N2,     KC.N3,     KC.N4,     KC.N5,                           KC.N6,     KC.N7,     KC.N8,    KC.N9,     KC.N0,     KC.PPLS,
    #     KC.PIPE,   KC.EXLM,   KC.AT,     KC.HASH,   KC.DLR,    KC.PERC,                         KC.CIRC,   KC.AMPR,   KC.PAST,  XXXXXXX,   XXXXXXX,   KC.EQL,
    #     XXXXXXX,   XXXXXXX,   XXXXXXX,   KC.LCBR,   KC.LBRC,   KC.LPRN,                         KC.RPRN,   KC.RBRC,   KC.RCBR,  XXXXXXX,   KC.BSLS,   KC.ENT,
    #     _______,   XXXXXXX,   _______,   _______,                                               _______,   KC.DEL,    XXXXXXX,  _______,
    # ],

    [  # lower: sym/num
        _______,   KC.EXLM,   KC.AT,     KC.HASH,   KC.DLR,    KC.LPRN,                         KC.RPRN,   KC.N7,     KC.N8,    KC.N9,     KC.PAST,   KC.PPLS,
        KC.PIPE,   KC.CIRC,   KC.AMPR,   KC.PAST,   KC.PERC,   KC.LBRC,                         KC.RBRC,   KC.N4,     KC.N5,    KC.N6,     XXXXXXX,   KC.EQL,
        XXXXXXX,   KC.RGB_MODE_RAINBOW,  KC.RGB_MODE_PLAIN,    KC.RGB_HUD,   KC.RGB_HUI,   KC.RGB_TOG,                          KC.N0,     KC.N1,     KC.N2,    KC.N3,     KC.BSLS,   KC.ENT,
        XXXXXXX,   XXXXXXX,   XXXXXXX,   _______,                                               _______,   KC.DEL,    XXXXXXX,  XXXXXXX,
    ],

    [  # raise: fn/nav
        KC.F1,     KC.F2,     KC.F3,     KC.F4,     KC.F5,     KC.F6,                           KC.F7,     KC.F8,     KC.F9,    KC.F10,    KC.F11,    KC.F12,
        XXXXXXX,   XXXXXXX,   XXXXXXX,   XXXXXXX,   XXXXXXX,   XXXXXXX,                         KC.VOLU,   PREVWRD,   KC.UP,    NEXTWRD,   KC.GRV,    KC.PGUP,
        XXXXXXX,   XXXXXXX,   XXXXXXX,   XXXXXXX,   XXXXXXX,   KC.PSCR,                         KC.VOLD,   KC.LEFT,   KC.DOWN,  KC.RIGHT,  XXXXXXX,   KC.PGDOWN,
        ADJUST,    XXXXXXX,   XXXXXXX,   _______,                                               _______,   XXXXXXX,   XXXXXXX,  XXXXXXX,
    ],

]

# Main
if __name__ == '__main__':
    print(keyboard.extensions)
    print(keyboard.modules)
    keyboard.go()

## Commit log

2022-11-13 Add stl files for AtreuSLB+
    [AtreuSLB50-BottomLeft.stl, AtreuSLB50-BottomRight.stl, AtreuSLB50-Foot.stl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]
2022-11-13 Move AtreuSLB+ stl files to rev1 foder
    [AtreuSLB50-BottomLeft.stl, AtreuSLB50-BottomRight.stl, AtreuSLB50-Foot.stl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]
2022-11-17 Update layers and encoders
2023-02-19 Add JeegVa44 ErgoZero Handwired Mechanical Keyboard
    [JeegVa44ErgoZero-CaseL.step, JeegVa44ErgoZero-CaseR.step, JeegVa44ErgoZero-ErgoFoot.step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]
2023-02-19 Add slits cover cad files
    [JeegVa44ErgoZero-SlitsCoverL.step, JeegVa44ErgoZero-SlitsCoverL.stl, JeegVa44ErgoZero-SlitsCoverR.step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]
2023-03-13 Move PrintScreen out of the way
2023-03-26 Add rubber feet to BOM and tech drawing
2023-04-07 Add no-slits version of stl and step files
    [JeegVa44ErgoZero-CaseL-noSlits.step, JeegVa44ErgoZero-CaseR-noSlits.step]
2024-01-11 Add cad models, minor update to README
    [Saru48wPlus - Badge.step, Saru48wPlus - Badge.stl, Saru48wPlus - Bottom Logo filler.step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]
2024-02-09 Add wiring diagram for Saru48
2024-02-16 Update README.md with BOM and FW links
